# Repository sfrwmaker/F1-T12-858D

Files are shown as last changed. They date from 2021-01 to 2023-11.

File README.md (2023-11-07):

# F1-T12-858D
Soldering station for hakko t12 tips + 858D rework station

The project description is available here: https://www.hackster.io/sfrwmaker/stm32-based-soldering-and-rework-station-e3955b

REVISION HISTORY:

Nov 2019. First release created

Jan 2020. Second release created
  - Minor changes in the controller schematics
  - Now the Hot Air Gun reed switch controls working mode
  - The soldering iron can keep working while Hot Air Gun mode
  - Screen saver feature implemented
  
Jan 2020. Some updates of the second release
  - Minor changes in the controller schematics
  - Buzzer is always on issue fixed

Feb 11 2020. Error on Op-amp label on schematics fixed. LM328 - > LM358

Mar 23 2020. New firmware release, 2.02. See detailed description on the project page.
  - Updated Hot Air Gun cooling procedure
  - Debug mode added allowing monitoring of the internal parameters

Apr 17 2020. New firmware release, 2.03. See detailed description on the project page.
  - Two mode hardware switch supported: REED and TILT. Tilt switch algorithm updated. 
  - Fixed issue 'jammed on tip selection screen'. Now the main menu reacheble from tip selection mode by long press.
  - Ambient temperature and tilt switch readings now are available on debug screen.
  - Controller without soldering handle connected starts working in Hot Air Gun mode.

Apr 29 2020. New firmware release, 3.00. See detailed description on the project page.
  - Optional 220v safety relay added.
  - Rotary encoder acceleration deactivated.

May 12 2020. New firmware release, 3.01. See detailed description on the project page.
  - Standby mode issues fixed.
  - Temperature step feature added.
  
June 03 2020. New firmaware release, 3.02.
  - Hot Air GUN start issue fixed. The power is supplied to the Hot Gun in 1 second after it activated allowing enabling AC relay.
  - "About" menu item issue fixed. Now this menu is available.
  - Tilt switch procedures reviewed and updated.
  - The standby mode separated from main working mode and implemented as a new one.
  - Screen saver timeout now is a single entity. It is no longer depended on mode switching. To return to the normal screen mode, touch the encoder.
  - Software automatic power off procedure reviewed and updated. The controller can power off the iron in case of no tilt switch available.
  - Accelerated mode of rotary encoder implemented in setting low power temperature procedure in the main menu.
  
  Jan 03 2021. New firmware release, 4.00.
  - Display initialization method chhanged. Now the rotation parameter is inside the contstuctor in display.cpp.
  - Added support for 'Guarantee cool gun' feature. New feature requires the hardware to be updated.
    With new hardware schematics the controller guarantees the Hot Air Gun cooled before shutdown.
    You can put Hot Air Gun to the base then switch off the main power switch and leave your working place.
    The controller will switch-off the Hot Air Gun, waits till the Hot Air gun cooled and power-off itself.
    The new firmware release suports old hardware also. Of course, new 'guarantee cool gun feature' will not be available on old hardware.
    
  Jan 30 2021. New hardware and firmware release, 4.01. The schematics with relay has been simplified.
  - Support for 'Guarantee cool gun' feature changed. New feature requires the hardware to be updated. See stm32_T12+858D_v4.sch file in the eagle directory.
  
  Feb 01 2021. Release 4.02.
  - Fixed controller hangs after Hot Air Gun cooled issue.
  
  Apr 28 2021. Release 4.03.
  - Debug information about AC zero events added to the debug mode
  
  May 25 2021. Release 4.04.
  - New feature added. Now it is possible to manage soldering iron while in hot air gun mode. If the "keep iron" option is enabled in main menu, long-press the encoder toggles the soldering iron.
 
  May 30 2021. Release 4.05.
  - Automatic startup mode implemented. The soldering iron would power-up when the power applied to the controller if mode activated.
  - Boost mode updated. Now boost duration time can be increment by 20 seconds upto 320 seconds. Boost mode temperature now more stable.

  Jun 02 2021. Release 4.06
  - No "about" item menu bug fixed
  
  Sep 21 2021. Release 4.07
  - Support for system clock checking procedure added. The controller checks its clock speed at startup. In case the ckock is lower than 72 MHz, the error message will be displayed. To return to the working mode long press the encoder.
  
  Sep 22 2021. Revert to release 4.06
  - The controller speed inialized correctly alwas, the speed test is not necessary.
  - Some followers reported the new firmware does not work.
  - Restore old source files, rebuild the project. Perhaps, the issue is about the flash limit of the stm32 microcontroller.
 
 Apr 01 2022. Release 4.07
 - Rotaruy encoder manager improved
 - New PID parameters for the Hot Air Gun caliration procedure applied
 - New TIP, T12-D32 added to the tip list

 Nov 07 2023. Release 4.08
 - The CubeMX file and project are mirgated to STM32CubeIDE.
 - Implemented new PID algorithm, trying to prevent overheating the soldering iron during heating up.
 - Faster heat-up procedure of soldering iron.
 - New manage procedure for Hot Air Gun imported from my recent project of soldering station with JBC tips.

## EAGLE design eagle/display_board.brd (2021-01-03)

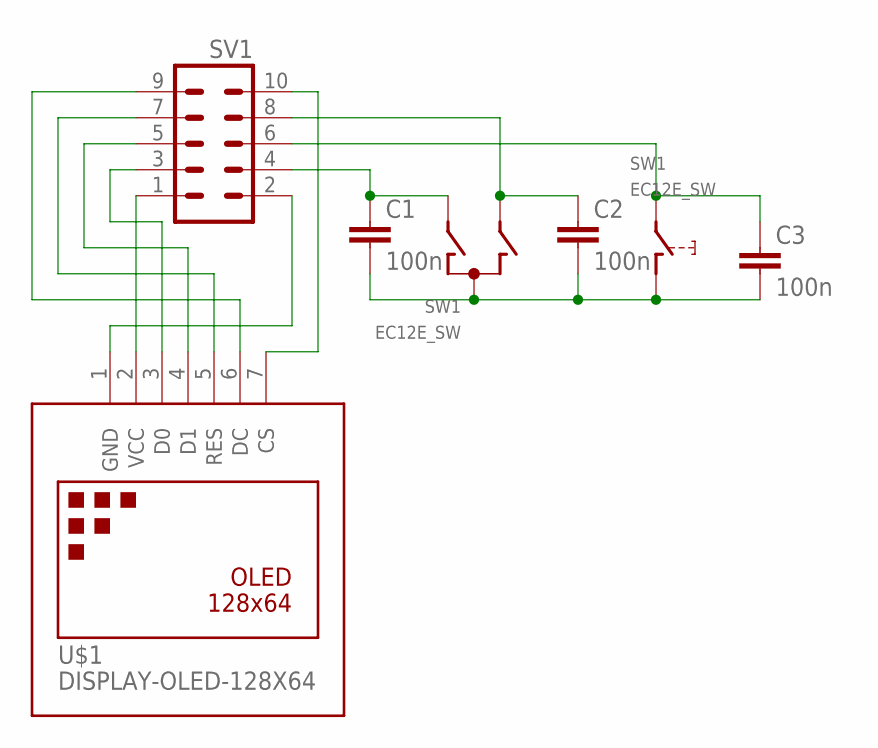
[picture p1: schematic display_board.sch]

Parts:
C1, C2, C3: 100n; C1206
SV1: MA05-2
SW1: EC12E_SW; ALPS_EC12E_SW
U$1: DISPLAY-OLED-128X64

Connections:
unnamed: SV1.1, U$1.2 (VCC)
unnamed: SV1.3, U$1.3 (D0)
unnamed: SV1.5, U$1.4 (D1)
unnamed: SV1.7, U$1.5 (RES)
unnamed: SV1.9, U$1.6 (DC)
unnamed: SV1.2, U$1.1 (GND)
unnamed: C1.1, SV1.4, SW1.A
unnamed: C1.2, C2.2, C3.2, SW1.C, SW1.D (1)
unnamed: C2.1, SV1.8, SW1.B
unnamed: C3.1, SV1.6, SW1.E (2)
unnamed: SV1.10, U$1.7 (CS)

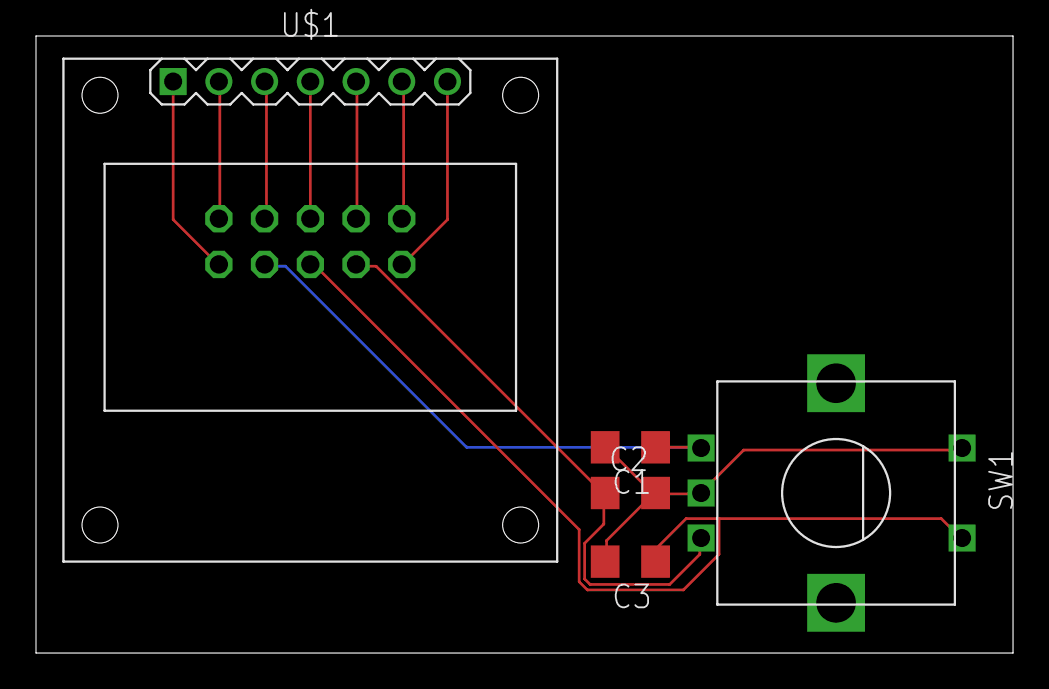
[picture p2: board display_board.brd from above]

Board: 2 copper layers, 54.3 x 34.3 mm, 6 parts (1 on the bottom side), 11 nets.

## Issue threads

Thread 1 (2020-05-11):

Bigger display

Vasilis-7, 2020-05-11:
I am thinking that a bigger display will help. In the market there are some economic color or black & white screens using the driver ILI9341. They have resolution up to 240*320 and 2.8"inches. Is it possible to add support for these ?

daohuaxiang4, 2020-08-12:
Hello! I want to restore the screen to normal display instead of rotating 180°. Which place in the display.cpp file should I modify?

sfrwmaker, 2020-12-20:
Hello!
I have investigated several displays on the market and you are right, the one based on ili9341 chip is the best choice because of variety of sizes: 2.2", 2.4" and 2.8". Yet it has SPI interface and has acceptable performance. The main problem is design. I am working on it, but still have no idea how to show all the parameters. Perhaps, this display can show the iron and hot gun parameters  simultaneously, but i do not know how.

Vasilis-7, 2020-12-22:
Thank you for your answer.
A big display is very useful. Because of that, I had started to make the hot air gun with the arduino and the hot iron with the arduino in the same box using 2 arduino mini pro, connected together through serial. The arduino which control the iron will not use its display, instead of that it will send the information by serial to the other arduino. The last one will send all the information on a LCD display 20 x 4.
But, a bigger display with the features of your project on the STM32 is a great chalenge !!!
I suggest, to use all the display for each unit during setup procedure. The view will be better for the graph. Also if the user is using only one, iron or air gun, you can use all the display with more details or better appearance. If the user wants to use both units, you can split the display horizonticaly with fewer details and simple appearance.
When the user uses only the hot air gun, you can have a tachometer for measuring the current temperature of the hot air gun, in the center like a odometer, the temperature goal, and beside, a second smaller tachometer like turbo indicator for the blower. When the iron is selected,  you can use something like this https://cdn.mos.cms.futurecdn.net/nvLu9ZnCboT3QeZGjo6NXh-970-80.jpg.
When the user needs both units, you can show him simple numbers with text and colors.
You can use colors to display the temperature grades or bars like an equalizer. The air indicator could be like a round pressure indicator with colors.
You can add a timer that will inform the user, in how many minutes or seconds the unit (iron, air gun or both) will turned off
You can have a graphical menu with buttons, a melody with a screen logo or a beautifull icon at startup.
Perhaps, later,  you can add a touch screen support on it.
Add also a software version view in the setup menu.

Vasilis

sfrwmaker, 2021-06-17:
Not an issue

Closed 2021-06-17.

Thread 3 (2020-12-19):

hardware reset when gun working

gyboy, 2020-12-19:
hey, Alexander, I  made one based on your hardware and software .I have changed nothing and it seems work well at the begining,however,when I used the gun for a while,the board automaticlly reset since I haved detected about 10ms low level signal on the reset pin,if I do not use the gun,it seems work well,have you ever met the problem? this IDE is not nice to me and I have problem to debug.

sfrwmaker, 2020-12-20:
Hello!
No one claimed this issue before.
Can you describe the problem in more detail?
How long it takes before switch-on the hot gun and reset event? I believe many followers use this rework station in hot gun mode for a long time and no one claimed such issue before.
How did you detect the 10ms reset (low ?) signal on reset pin? As far as i know, the reset pin is pulled-up on the bluepill board to 3.3v, yet it does not connected to anything else. Also, no watch-dog timer used in the firmware. So it is hard to imagine what is the issue root. I will investigate this issue.

gyboy, 2020-12-21:
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
I just make the station and do not do any calibration before,when I move the gun from the hook , the fan is on and every setting is defalt,(I do not connect thesolder since I just want to check the fan function while the AC zero and relay pin is still work)After about 1min the hardware started reset repetly.I try again today and find that even I remove the gun and just leave the AC zero&delay connect,the station will still reset after about 1min.

> How long it takes before switch-on the hot gun and reset event? I believe many followers use this rework station in hot gun mode for a long time and no one claimed such issue before.
1 min, I forgot to tell you that I just changed 3 pin to fit you T12 project .I modefied GUN_REED_Pin to PA7, ENCODER_R_Pin to PB3 TILT_SW_Pin to PA8 just on main.h since they are just GPIO fuction.Besides,I modified the Encode direction too.

> How did you detect the 10ms reset (low ?) signal on reset pin? As far as i know, the reset pin is pulled-up on the bluepill board to 3.3v, yet it does not connected to anything else. Also, no watch-dog timer used in the firmware. So it is hard to imagine what is the issue root. I will investigate this issue.
I use the oscilloscope and found the low level on reset pin, since my borad has also added the RC delay on reset pin.
besides,when I use the gun menu and select calibration and then push the button to turn on the gun,the sreen will show ERROR after about 6 seconds.

sfrwmaker, 2020-12-21:
Sorry, I cannot debug modified hardware project. Because i have no such hardware.
You can use debug mode to investigate the issue.

gyboy, 2020-12-21:
> Sorry, I cannot debug modified hardware project. Because i have no such hardware.
> You can use debug mode to investigate the issue.

Another strange problem is that the gun temp channel which is PA5 keep zero no matter floating or connect to gun, even connected to 3V3,maybe I should resolve this first.

gyboy, 2020-12-22:
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

hey,bro,I think I have found the problem,but I still have something to enquire you,it looks like the GUN TEMP  ADC doesn't work well even I measured floating voltage on the pin however the buffer can not detect it,I am looking for the problem for futher,maybe other ADC have same problem.I migrate the project to high version,maybe something wrong happened.I want to know have you set the ADC1 and ADC2 global interrupts,since in my cubeMX it is disabled,canyou tell me other settings about ADC too,the pic on the web is not complete,thanks.

sfrwmaker, 2020-12-22:
Hello!
The controller should be tuned in terms of potentiometers R5 and R19. And to debug the hardware problems, you can use debug mode (called through 'About' menu). Here you can see the raw values the controller reads from the hardware.

gyboy, 2020-12-22:
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

thanks,I can not go to turn mode now since when I turn on the gun for a while, hard reset will happened.besides, the ADC is still have problem now. I found this problems just on the About menu.I have made you IRON  project before and it works well ,while when I made this station just use same components,problems met on ADC.It seems ADC hardware is simple,but the soft is a little complex,why you set ADC1 and ADC2 to acquire several channels in different interval while use just one adc and continuosly sample 5 channels in one interrupt

sfrwmaker, 2020-12-22:
Hello!
There is an incorrect call of ADC conversion using DMA in the source code. But it works fine, so i decided to keep this error for a while. Perhaps some day i will release new version where this error will be fixed.
I have tried to change the ADC channels while program work but failed with that so i decided to fix the channels for every measurement. If you check the CubeMX, you can see the ADC1 used to check current through the iron and through fan, gun temperature and ambient temperature. While ADC2 is used to check the iron temperature only. The soldering iron temperature can change quickly so i decided to use average value of 4 temperature samples.

gyboy, 2020-12-25:
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

thanks!
That's the problem ,it seems that all my chips on hand worked not well like yours, I tried to make one same circuit like yours on the bread board,it also doesn't work,the phenomenon is that that gun temp is not update brfore I got in the debug menu,on the main show the gun temp  maintain 25 which is same with NTC ,no matter I connect it to VCC or GND .

I also tried to trance the program,it looked like the "buff[ADC_BUFF_SZ]" catched the right value but updated fail to "gun_temp"
can you describe the error more detaily,I am considering whether I need to use the ADC DMA.

sfrwmaker, 2020-12-26:
Hello!
First, the hardware issues should be fixed. Check the voltage on pins #3 and pin#1 od AD823 op amp. This is a gun temperature. Also, check the voltage on pin #5 and pin#7 of AD823. This is a iron temperature. Then check the voltage on pin #3 and pin #1 of lm358 this should be the current through the hot air gun fan (when the gun activated) and voltage on pins #5 and #7 - this is a current through the iron. Usually, the hardware is a source of all problems in this project. Sometimes the people buy fake op-amps or other components. Another problem can be fake stm32 board. I have several garbage boards based on cks32 micro controller. They are about compatible with stm32, but does not supported by the development tools.

gyboy, 2021-01-19:
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

thanks, I have made sure that the hardware is ok since I have used it on the STM32 T12 project, besides,recently I was studying your code  and tried to do some debug use segger RTT, I disconnect the ADC pin and amp so I can rule out the hardware problem.which means that now the adc pin is float. The result is that the in the "HAL_ADC_ConvCpltCallback" ,I can read the "buff" value and then it should use "core.hotgun.updateTemp(gun_temp);" to update,however ,when I print the "pHG->averageTemp()" in the "MWORK_GUN::loop" function, it stay 0 no matter I turn on the gun or off,but if I go to the "DEBUG" menu,the "pHG->averageTemp()" value will update both in segger RTT and OLED.

sfrwmaker, 2021-01-19:
What exactly do you see on the debug screen?

gyboy, 2021-01-20:
>
>
> What exactly do you see on the debug screen?

I can see the GUN_TEMP jump from 0 to another value,which means before the value is always zero that I can see from segger RTT directly.

gyboy, 2021-02-04:
> What exactly do you see on the debug screen?

Hey,man,I have solved the issue.Cause the input signal has too many noise from the gun that the opm can not process the signal.But there is another problem that I need to enquire you,in the eagle project you use MOC3052 to control the AC line, while MOC3052 has non-zero-cross control but the component symbol in your circuit looks like MOC3062 that has zero-cross detect.The problem I met was that when I connent the heat gun,the AC output is zero,if I disconnected the heat load, the output 220V is ok.I measured the head load is about 70ohm that seems to work well,but I do not know why AC output missed.Could you tell which one do you used,3052 or 3062,thks.

sfrwmaker, 2021-02-04:
Hello!

I used MOC3061 variant. It is not necessary to use zero-cross-detection feature because, there is a zero detector built on 4N25 IC in this project. The know-how is that the Hot Air Gun controller "cuts" whole AC half-period waves starting from zero, then to maximum amplitude and again to zero. The controller detects AC zero crossing time and supplies the power to the MOC3052.
Is the Hot Air Gun Fan rotating? The controller should detect the current through the fan to supply the power the the heater circuit.  To detect the current through the fan, the controller check the voltage drop on R27 resister. Please, check the voltage on pins #3 and #1 of lm358.

gyboy, 2021-02-05:
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

The fan works well and I can change the speed,maybe I should detect the fan current opm output.I have measured the controller zero cross input and heater output,both looks well as shown below.
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

- [ ]

sfrwmaker, 2021-02-06:
Hello!
Did you mean voltage on PA11 pin of bluePill board? For sure, the controller is working fine. Please check your TRIAC cirquit.

sfrwmaker, 2021-06-17:
Fixed

Closed 2021-06-17.

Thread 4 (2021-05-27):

JBC 210 245  iron support

mojinyinhu, 2021-05-27:
hi，Can you add JBC 210 245 iron core support？

sfrwmaker, 2021-05-27:
Not planned. Usually universal tool is worse than dedicated one.

mojinyinhu, 2021-06-05:
936 jbc245 jbc210 these are all 24 V power supply. Under the current circuit, we can detect the resistance value of the heating core of these soldering irons, do automatic detection, and automatically adapt to the maximum power. At present, we see that the general welding platform (supporting 936, T12, JBC) circuit is PWM control scheme, and there are also related products. We hope that we can adapt the software to make the general welding platform, and the power of t12 72w is limited after all, It's not easy to deal with large solder joints. 245 150W power is very good, and the temperature recovery effect is also very good.  hope this scheme can be considered

The attachment is a reference scheme
[Uploading 四合一JBC  T12 936 OLED1.3寸 工作等级焊台资料.zip…]()

sfrwmaker, 2021-06-17:
Not an issue.

Closed 2021-06-17.

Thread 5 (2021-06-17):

can you add 3 memory state like quick station

labotecno, 2021-06-17:
hello i see your project  and i like it , can you add 3 or 4 memory state , for heat gun like quick hot air station ?

sfrwmaker, 2021-06-17:
It is much convenient to discuss the project on hackster.io. :)

sfrwmaker, 2021-06-17:
Not an issue

Closed 2021-06-17.

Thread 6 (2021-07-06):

exclude private variable i_summ

enjoyneering, 2021-07-06:
Why keep "i_summ" in memory when it always changes and used locally in PID::reqPower()?

sfrwmaker, 2021-07-06:
Perhaps, this variable used in beta version or so. Just did not optimized.:) Will be fixed in future release or in future project.
Thank you for your report.

enjoyneering, 2021-07-07:
Good. Thank you for awesome project.

Closed 2021-07-07.

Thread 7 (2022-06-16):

PID control strategy，Temperature overshoot of air gun soldering iron

mojinyinhu, 2022-06-16:
hello，If it is found that the temperature of the air gun soldering iron is overshoot, can the segmented PID be modified and used: when the temperature difference is >100 ℃, heat at full speed; Radical PID when the temperature difference is 30~100 ℃; Conservative PID when temperature difference <30 ℃;

sfrwmaker, 2022-06-16:
This strategy does not work.

sfrwmaker, 2024-01-12:
New firmware manages the soldering iron and hot air gun more accurately.

Closed 2024-01-12.

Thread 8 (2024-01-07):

can have only T12 firmware binary use?

myvcgit, 2024-01-07:
i had F1-T12-858D pcb and finished t12 part, but this  firmware work incorrect.
can we have only t12 firmware for this pcb?
thank you!

sfrwmaker, 2024-01-07:
Can you describe the issue in more details? What exactly is working incorrectly?
And no, the firmware was developed for described hardware. If you do not want to use hot air gun, you can choose another project. Please see on hackster.io, there are many other soldering projects using Hakko T12 tips.

myvcgit, 2024-01-13:
thank you.
i found ur t12 project.
https://github.com/sfrwmaker/hakko_t12_stm32

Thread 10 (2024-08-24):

STM32CubeIDE compilation error,

daohuaxiang4, 2024-08-24:
Hope to write a correct compilation process to help me

sfrwmaker, 2024-08-25:
Can you contact me at hackster.io, please? You can write a private message to me or post new comment in the project discussion page.

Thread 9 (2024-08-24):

STM32CubeIDE compilation error, want to write a correct compilation process

daohuaxiang4, 2024-08-24:

Closed 2024-08-24.

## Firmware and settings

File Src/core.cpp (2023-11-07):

/*
 * core.cpp
 *
 *  Created on: 30 aug 2019
 *      Author: Alex
 */

#include <string.h>
#include "core.h"
#include "hw.h"
#include "mode.h"
#include "stat.h"
#include "oled.h"
#include "tools.h"
#include "buzzer.h"

#include "display.h"
#include <math.h>

#define ADC_CONV 	(4)										// Activated ADC Ranks Number (hadc2.Init.NbrOfConversion)
#define ADC_LOOPS	(2)										// Number of ADC conversion loops. Should be even
#define ADC_BUFF_SZ	(2*ADC_CONV*ADC_LOOPS)

extern ADC_HandleTypeDef	hadc1;
extern ADC_HandleTypeDef	hadc2;
extern TIM_HandleTypeDef	htim1;
extern TIM_HandleTypeDef	htim2;
extern TIM_HandleTypeDef	htim4;

typedef enum { ADC_IDLE, ADC_CURRENT, ADC_TEMP } t_ADC_mode;
volatile static t_ADC_mode	adc_mode = ADC_IDLE;
volatile static uint16_t	buff[ADC_BUFF_SZ];
volatile static	uint32_t	tim1_cntr	= 0;				// Previous value of TIM1 counter. Using to check the TIM1 value changing
volatile static	bool		ac_sine		= false;			// Flag indicating that TIM1 is driven by AC power interrupts on AC_ZERO pin
volatile static uint8_t		check_count	= 1;				// Decrement from check_period to zero by TIM2. When become zero, force to check the IRON connectivity
volatile static bool		clock_ok	= true;				// Flag indicating the system clock is working at 72 MHz (see RTC_IRQHandler()
const static uint16_t  		max_iron_pwm	= 1960;			// Max value should be less than TIM2.CHANNEL3 value by 20
const static uint16_t  		max_gun_pwm		= 99;			// TIM1 period. Full power can be applied to the HOT GUN
const static uint16_t		check_iron_pwm	= 1;			// This power should be applied to check the current through the IRON
const static uint8_t		check_period	= 6;			// TIM2 loops between check current through the iron
const static	uint32_t	check_sw_period = 100;			// IRON switches check period, ms

static HW		core;										// Hardware core (including all device instances)

// MODE instances
static	MSTBY_IRON		standby_iron(&core);
static	MWORK_IRON		work_iron(&core);
static  MLOW_POWER		low_power(&core);
static	MBOOST			boost(&core);
static	MSLCT			select(&core);
static	MTACT			activate(&core);
static	MCALIB			calib_auto(&core);
static	MCALIB_MANUAL	calib_manual(&core);
static	MCALMENU		calib_menu(&core, &calib_auto, &calib_manual);
static	MTUNE			tune(&core);
static	MFAIL			fail(&core);
static	MMBST			boost_setup(&core);
static	MTPID			pid_tune(&core);
static	MENU_GUN		gun_menu(&core, &calib_manual, &tune, &pid_tune);
static	MWORK_GUN		work_gun(&core);
static  MABOUT			about(&core);
static  MDEBUG			debug(&core);
static	MMENU			main_menu(&core, &boost_setup, &calib_menu, &activate, &tune, &pid_tune, &gun_menu, &about);
static	MODE*           pMode = &standby_iron;

bool isACsine(void) 	{ return ac_sine; }

// Synchronize TIM2 timer to AC power
uint16_t syncAC(void) {
	uint32_t to = HAL_GetTick() + 300;						// The timeout
	uint16_t nxt_tim1	= TIM1->CNT + 2;
	if (nxt_tim1 > 99) nxt_tim1 -= 99;						// TIM1 is clocked by AC zero crossing signal, period is 99.
	while (HAL_GetTick() < to) {							// Prevent hang
		if (TIM1->CNT == nxt_tim1) {
			TIM2->CNT = 0;									// Synchronize TIM2 to AC power zero crossing signal
			break;
		}
	}
	// Checking the TIM2 has been synchronized
	to = HAL_GetTick() + 300;
	nxt_tim1 = TIM1->CNT + 2;
	if (nxt_tim1 > 99) nxt_tim1 -= 99;
	while (HAL_GetTick() < to) {
		if (TIM1->CNT == nxt_tim1) {
			return TIM2->CNT;
		}
	}
	return TIM2->ARR+1;										// This value is bigger than TIM2 period, the TIM2 has not been synchronized
}

void SCRSAVER::reset(void) {
	if (to > 0) {
		scr_save_ms = HAL_GetTick() + (uint32_t)to * 60000;
	} else {
		scr_save_ms = 0;								// Disable screen saver
	}
	scr_saver = false;
}

bool SCRSAVER::scrSaver(void) {
    if (scr_save_ms && !scr_saver && HAL_GetTick() >= scr_save_ms) {
    	scr_saver = true;
    }
    return scr_saver;
}

CFG_STATUS HW::init(void) {
	dspl.init();
	iron.init();
	hotgun.init();
	encoder.addButton(ENCODER_B_GPIO_Port, ENCODER_B_Pin);
	CFG_STATUS cfg_init = 	cfg.init();
	PIDparam pp   		= 	cfg.pidParams(true);			// load IRON PID parameters
	iron.load(pp);
	pp					=	cfg.pidParams(false);			// load Hot Air Gun PID parameters
	hotgun.load(pp);
	buzz.activate(cfg.isBuzzerEnabled());
	scrsaver.init(cfg.getScrTo());							// Screen saver timeout can be reloaded via main menu, see MMENU::loop()
	return cfg_init;
}

extern "C" void setup(void) {
	CFG_STATUS cfg_init = core.init();						// Initialize the hardware structure before start timers

	HAL_ADCEx_Calibration_Start(&hadc1);					// Calibrate both ADCs
	HAL_ADCEx_Calibration_Start(&hadc2);
	HAL_TIM_PWM_Start(&htim1, TIM_CHANNEL_4);				// PWM signal of Hot Air Gun
	HAL_TIM_OC_Start_IT(&htim1,  TIM_CHANNEL_3);			// Calculate power of Hot Air Gun interrupt
	HAL_TIM_PWM_Start(&htim2, TIM_CHANNEL_1);				// PWM signal of the IRON
	HAL_TIM_PWM_Start(&htim2, TIM_CHANNEL_2);				// PWM signal of FAN (Hot Air Gun)
	HAL_TIM_OC_Start_IT(&htim2,  TIM_CHANNEL_3);			// Check the current through the IRON and FAN, also check ambient temperature
	HAL_TIM_OC_Start_IT(&htim2,  TIM_CHANNEL_4);			// Calculate power of the IRON
	HAL_TIM_PWM_Start(&htim4,    TIM_CHANNEL_4);			// PWM signal for the buzzer

	// Setup main mode parameters: return mode, short press mode, long press mode
	standby_iron.setup(&select, &work_iron, &main_menu);
	work_iron.setup(&standby_iron, &standby_iron, &boost);
	low_power.setup(&standby_iron, &work_iron, &work_iron);
	boost.setup(&work_iron, &work_iron, &work_iron);
	select.setup(&standby_iron, &activate, &main_menu);
	activate.setup(&standby_iron, &standby_iron, &main_menu);
	calib_auto.setup(&standby_iron, &standby_iron, &standby_iron);
	calib_manual.setup(&calib_menu, &standby_iron, &standby_iron);
	calib_menu.setup(&standby_iron, &standby_iron, &standby_iron);
	tune.setup(&standby_iron, &standby_iron, &standby_iron);
	fail.setup(&standby_iron, &standby_iron, &standby_iron);
	boost_setup.setup(&main_menu, &main_menu, &standby_iron);
	pid_tune.setup(&standby_iron, &standby_iron, &standby_iron);
	gun_menu.setup(&main_menu, &standby_iron, &standby_iron);
	main_menu.setup(&standby_iron, &standby_iron, &standby_iron);
	about.setup(&standby_iron, &standby_iron, &debug);
	debug.setup(&standby_iron, &standby_iron, &standby_iron);

	standby_iron.setGunMode(&work_gun);
	work_iron.setGunMode(&work_gun);
	work_iron.setLowPowerMode(&low_power);
	work_gun.setIronModes(&standby_iron, &work_iron);

	switch (cfg_init) {
		case	CFG_NO_TIP:
			pMode	= &activate;							// No tip configured, run tip activation menu
			break;
		case	CFG_READ_ERROR:								// Failed to read EEPROM
			core.dspl.errorMessage("EEPROM\nread\nerror");
			pMode	= &fail;
			break;
		default:
			if (core.cfg.isAutoStart())
				pMode = &work_iron;
			break;
	}

	syncAC();												// Synchronize TIM2 timer to AC power
	HAL_Delay(1000);										// Wait till hardware status updated
	pMode->init();
}


extern "C" void loop(void) {
	static uint32_t AC_check_time	= 0;					// Time in ms when to check TIM1 is running
	static uint32_t	check_sw		= 0;					// Time when check iron switches status (ms)

	if (HAL_GetTick() > check_sw) {
		check_sw = HAL_GetTick() + check_sw_period;
		GPIO_PinState pin = HAL_GPIO_ReadPin(TILT_SW_GPIO_Port, TILT_SW_Pin);
		core.iron.updateReedStatus(GPIO_PIN_SET == pin);		// Update T12 TILT switch status
		pin = HAL_GPIO_ReadPin(GUN_REED_GPIO_Port, GUN_REED_Pin);
		core.hotgun.updateReedStatus(GPIO_PIN_SET == pin);	// Switch active when the Hot Air Gun handle is off-hook
	}

	MODE* new_mode = pMode->returnToMain();
	if (new_mode && new_mode != pMode) {
		core.buzz.doubleBeep();
		core.iron.switchPower(false);
		TIM2->CCR1	= 0;
		pMode = new_mode;
		pMode->init();
		return;
	}
	new_mode = pMode->loop();
	if (new_mode != pMode) {
		if (new_mode == 0) new_mode = &fail;				// Mode Failed
		core.iron.switchPower(false);
		core.hotgun.switchPower(false);
		TIM2->CCR1	= 0;
		pMode = new_mode;
		pMode->init();
	}

	// If TIM1 counter has been changed since last check, we received AC_ZERO events from AC power
	if (HAL_GetTick() >= AC_check_time) {
		ac_sine		= (TIM1->CNT != tim1_cntr);
		tim1_cntr	= TIM1->CNT;
		AC_check_time = HAL_GetTick() + 41;					// 50Hz AC line generates 100Hz events. The pulse period is 10 ms
	}
}

static bool adcStart(t_ADC_mode mode) {
    if (adc_mode != ADC_IDLE) {								// Not ready to check analog data; Something is wrong!!!
    	TIM2->CCR1 = 0;										// Switch off the IRON
    	TIM1->CCR4 = 0;										// Switch off the Hot Air Gun
		return false;
    }
	HAL_ADC_Start(&hadc2);
    HAL_ADCEx_MultiModeStart_DMA(&hadc1, (uint32_t*)buff, ADC_CONV*ADC_LOOPS);
	adc_mode = mode;
	return true;
}

/*
 * IRQ handler
 * on TIM1 Output channel #3 to calculate required power for Hot Air Gun
 * on TIM2 Output channel #3 to read the current through the IRON and Fan of Hot Air Gun
 * also check that TIM1 counter changed driven by AC_ZERO interrupt
 * on TIM2 Output channel #4 to read the IRON, HOt Air Gun and ambient temperatures
 */
extern "C" void HAL_TIM_OC_DelayElapsedCallback(TIM_HandleTypeDef *htim) {
	if (htim->Instance == TIM1 && htim->Channel == HAL_TIM_ACTIVE_CHANNEL_3) {
		uint16_t gun_power	= core.hotgun.power();
		TIM1->CCR4	= constrain(gun_power, 0, max_gun_pwm);
	}
	if (htim->Instance == TIM2) {
		if (htim->Channel == HAL_TIM_ACTIVE_CHANNEL_3) {
			if (TIM2->CCR1 || TIM2->CCR2)					// If IRON of Hot Air Gun has been powered
				adcStart(ADC_CURRENT);
		} else if (htim->Channel == HAL_TIM_ACTIVE_CHANNEL_4) {
			adcStart(ADC_TEMP);
		}
	}
}

/*
 * IRQ handler of ADC complete request. The data is in the ADC buffer (buff)
 * Data read by 8 slots interleaved: adc1-rank1, adc2-rank1, adc1-rank2, adc2-rank2, ..., adc1-rank4, adc2-rank4
 * The ADC buffer would have the following fields (see MX_ADC1_Init() MX_ADC2_Init() in main.c)
 * ADC1:			ADC2:
 * iron_current		iron_temp
 * fan_current		iron_temp
 * gun_temp			iron_temp
 * ambient			iron_temp
 */
extern "C" void HAL_ADC_ConvCpltCallback(ADC_HandleTypeDef* hadc) {
	if (hadc->Instance != ADC1) return;
	HAL_ADCEx_MultiModeStop_DMA(&hadc1);
	HAL_ADC_Stop(&hadc2);
	if (adc_mode == ADC_TEMP) {								// Read the temperatures only, the current should be ignored
		volatile uint32_t iron_temp	= 0;
		volatile uint32_t gun_temp	= 0;
		volatile uint32_t ambient 	= 0;
		for (uint8_t i = 0; i < ADC_BUFF_SZ; i += 2*ADC_CONV) {
			iron_temp	+= buff[i+1] + buff[i+3] + buff[i+5] + buff[i+7];
			gun_temp	+= buff[i+4];
			ambient		+= buff[i+6];
		}
		iron_temp 	+= (ADC_LOOPS*ADC_CONV)/2;				// Round the result
		iron_temp 	/= ADC_LOOPS*ADC_CONV;
		gun_temp 	+= ADC_LOOPS/2;							// Round the result
		gun_temp  	/= ADC_LOOPS;
		ambient 	+= ADC_LOOPS/2;							// Round the result
		ambient  	/= ADC_LOOPS;
		core.iron.updateAmbient(ambient);

		uint8_t min_iron_pwm = 0;							// By default do not power the IRON to check connectivity
		if (--check_count == 0) {							// It is time to check IRON is connected or not
			check_count	= check_period;
			min_iron_pwm = check_iron_pwm;
		}
		if (core.iron.isConnected()) {
			uint16_t iron_power = core.iron.power(iron_temp);
			TIM2->CCR1	= constrain(iron_power, min_iron_pwm, max_iron_pwm);

		} else {
			TIM2->CCR1	= min_iron_pwm;						// Sometimes supply minimum power to the IRON to check connectivity
		}
		core.hotgun.updateTemp(gun_temp);					// Update average Hot Air Gun temperature. Apply the power by TIM1.CNANNEL3 interrupt
	} else if (adc_mode == ADC_CURRENT) {					// Read the currents, the temperatures should be ignored
		volatile uint32_t iron_curr	= 0;
		volatile uint32_t fan_curr 	= 0;
		for (uint8_t i = 0; i < ADC_BUFF_SZ; i += 2*ADC_CONV) {
			iron_curr	+= buff[i];
			fan_curr	+= buff[i+2];
		}
		iron_curr	+= ADC_LOOPS/2;							// Round the result
		iron_curr	/= ADC_LOOPS;
		fan_curr	+= ADC_LOOPS/2;							// Round the result
		fan_curr	/= ADC_LOOPS;

		if (TIM2->CCR1)										// If IRON has been powered
			core.iron.updateCurrent(iron_curr);
		if (TIM2->CCR2)										// If Hot Air Gun Fan has been powered
			core.hotgun.updateCurrent(fan_curr);
	}
	adc_mode = ADC_IDLE;
}

extern "C" void HAL_ADC_ErrorCallback(ADC_HandleTypeDef *hadc) 				{ }
extern "C" void HAL_ADC_LevelOutOfWindowCallback(ADC_HandleTypeDef *hadc) 	{ }

// Encoder Rotated
extern "C" void EXTI0_IRQHandler(void) {
	core.encoder.encoderIntr();
	__HAL_GPIO_EXTI_CLEAR_IT(ENCODER_L_Pin);
}

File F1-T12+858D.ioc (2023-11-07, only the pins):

Mcu.UserName=STM32F103C8Tx
PA0-WKUP.GPIO_Label=IRON_POWER
PA0-WKUP.Signal=S_TIM2_CH1_ETR
PA1.GPIO_Label=FAN_POWER
PA1.Signal=S_TIM2_CH2
PA10.GPIO_Label=OLED_CS
PA10.Signal=GPIO_Output
PA11.GPIO_Label=GUN_POWER
PA11.Signal=S_TIM1_CH4
PA12.GPIO_Label=AC_ZERO
PA12.Signal=S_TIM1_ETR
PA13.Signal=SYS_JTMS-SWDIO
PA14.Signal=SYS_JTCK-SWCLK
PA15.GPIO_Label=AC_RELAY
PA15.Signal=GPIO_Output
PA2.GPIO_Label=IRON_CURRENT
PA2.Signal=ADCx_IN2
PA3.GPIO_Label=FAN_CURRENT
PA3.Signal=ADCx_IN3
PA4.GPIO_Label=IRON_TEMP
PA4.Signal=ADCx_IN4
PA5.GPIO_Label=GUN_TEMP
PA5.Signal=ADCx_IN5
PA6.GPIO_Label=AMBIENT
PA6.Signal=ADCx_IN6
PA8.GPIO_Label=GUN_REED
PA8.Signal=GPIO_Input
PA9.GPIO_Label=ENCODER_R
PA9.Signal=GPIO_Input
PB0.GPIO_Label=ENCODER_L
PB0.Signal=GPXTI0
PB1.GPIO_Label=ENCODER_B
PB1.Signal=GPIO_Input
PB10.GPIO_Label=OLED_RESET
PB10.Signal=GPIO_Output
PB11.GPIO_Label=OLED_DC
PB11.Signal=GPIO_Output
PB13.GPIO_Label=OLED_SCK
PB13.Signal=SPI2_SCK
PB15.GPIO_Label=OLED_SDA
PB15.Signal=SPI2_MOSI
PB3.GPIO_Label=TILT_SW
PB3.Signal=GPIO_Input
PB6.Signal=I2C1_SCL
PB7.Signal=I2C1_SDA
PB9.GPIO_Label=BUZZER
PB9.Signal=S_TIM4_CH4
PD0-OSC_IN.Signal=RCC_OSC_IN
PD1-OSC_OUT.Signal=RCC_OSC_OUT

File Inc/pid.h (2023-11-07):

/*
 * pid.h
 *
 *  Created on: 13 ���. 2019 �.
 *      Author: Alex
 */

#ifndef _PID_H
#define _PID_H

#include "main.h"
#include "stat.h"
#include "vars.h"

class PIDparam {
	public:
		PIDparam(int32_t Kp = 0, int32_t Ki = 0, int32_t Kd = 0);
		PIDparam(const PIDparam &p);
		int32_t	Kp					= 0;
		int32_t	Ki					= 0;
		int32_t	Kd					= 0;
};


/*  The PID algorithm 
 *  Un = Kp*(Xs - Xn) + Ki*summ{j=0; j<=n}(Xs - Xj) + Kd(Xn - Xn-1),
 *  Where Xs - is the setup temperature, Xn - the temperature on n-iteration step
 *  In this program the interactive formula is used:
 *    Un = Un-1 + Kp*(Xn-1 - Xn) + Ki*(Xs - Xn) + Kd*(Xn-2 + Xn - 2*Xn-1)
 *  With the first step:
 *  U0 = Kp*(Xs - X0) + Ki*(Xs - X0); Xn-1 = Xn;
 *  
 *  The default values of PID coefficients can be found in config.cpp
 */
class PID {
	public:
		PID(void) 											{ }
		void		load(const PIDparam &p);
		PIDparam	dump(void)								{ return PIDparam(Kp, Ki, Kd);			}
		void		pidStable(int32_t power)				{ this->power = power;					}
		void		init(uint16_t ms, uint8_t denominator_p = 11, bool heat_force = true);
		void 		resetPID(uint16_t t = 0);        		// reset PID algorithm history parameters
		int32_t 	reqPower(int16_t temp_set, int16_t temp_curr);
		int32_t  	changePID(uint8_t p, int32_t k);    	// set or get (if parameter < 0) PID parameter
		void		newPIDparams(uint16_t delta_power, uint32_t diff, uint32_t period);
	private:
		void  		debugPID(int t_set, int t_curr, long kp, long ki, long kd, long delta_p);
		uint32_t 	T 				= 20;					// Check IRON or Hot Air Gun period, ms (to calculate auto PID parameters)
		int16_t   	temp_h0			= 0;					// previously measured temperatures
		int16_t	  	temp_h1			= 0;
		int32_t  	power			= 0;					// The power iterative multiplied by denominator
		int32_t  	Kp 				= 10;					// The PID coefficients multiplied by denominator.
		int32_t     Ki 				= 10;
		int32_t		Kd				= 0;
		int32_t		Kp_force		= 10;					// Kp * 5
		int32_t		Ki_force		= 5;					// Ki / 10
		int16_t  	denominator_p	= 11;              		// The common coefficient denominator power of 2 (11 means 2048)
		bool		use_force		= true;					// Flag indicating to use forcibly heating mode
};

class PIDTUNE {
	public:
		PIDTUNE(void) : period(auto_pid_hist_length), temp_max(auto_pid_hist_length), temp_min(auto_pid_hist_length)		{ 	}
		void		start(uint16_t base_pwr, uint16_t delta_power, uint16_t base_temp, uint16_t delta_temp);
		uint16_t	run(uint32_t t);
		uint16_t	autoTuneLoops(void)						{ return loops; 						}
		uint32_t	autoTunePeriod(void)					{ return period.read();					}
		uint16_t	tempMin(void)							{ return temp_min.read();   			}
		uint16_t	tempMax(void)							{ return temp_max.read();   			}
		bool		periodStable(void);
	private:
		HIST		period;									// Average value of relay method oscillations period
		HIST		temp_max;								// Average value of maximum temperature
		HIST		temp_min;								// Average value of minimum temperature
		volatile	uint16_t	base_power		= 0;		// Base power value
		volatile 	uint16_t 	delta_power		= 0;		// PLUS delta power applied
		volatile	uint16_t	base_temp		= 0;		// Base temperature value
		volatile	uint16_t	delta_temp		= 0;		// The temperature limit (base_temp - delta_temp <= t <= base_temp + delta_temp)
		volatile	bool		app_delta_power	= false;	// Do apply delta power
		volatile	uint32_t	pwr_change		= 0;		// The time (ms) when tune extra power changed
		volatile	bool		check_max		= false;
		volatile	bool		check_min		= false;
		volatile 	uint16_t	t_max			= 0;
		volatile    uint16_t	t_min			= 0;
		volatile	uint16_t	loops			= 0;		// Whole tune oscillation loop count
};

#endif

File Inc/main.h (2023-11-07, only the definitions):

#define IRON_POWER_Pin GPIO_PIN_0
#define IRON_POWER_GPIO_Port GPIOA
#define FAN_POWER_Pin GPIO_PIN_1
#define FAN_POWER_GPIO_Port GPIOA
#define IRON_CURRENT_Pin GPIO_PIN_2
#define IRON_CURRENT_GPIO_Port GPIOA
#define FAN_CURRENT_Pin GPIO_PIN_3
#define FAN_CURRENT_GPIO_Port GPIOA
#define IRON_TEMP_Pin GPIO_PIN_4
#define IRON_TEMP_GPIO_Port GPIOA
#define GUN_TEMP_Pin GPIO_PIN_5
#define GUN_TEMP_GPIO_Port GPIOA
#define AMBIENT_Pin GPIO_PIN_6
#define AMBIENT_GPIO_Port GPIOA
#define ENCODER_L_Pin GPIO_PIN_0
#define ENCODER_L_GPIO_Port GPIOB
#define ENCODER_L_EXTI_IRQn EXTI0_IRQn
#define ENCODER_B_Pin GPIO_PIN_1
#define ENCODER_B_GPIO_Port GPIOB
#define OLED_RESET_Pin GPIO_PIN_10
#define OLED_RESET_GPIO_Port GPIOB
#define OLED_DC_Pin GPIO_PIN_11
#define OLED_DC_GPIO_Port GPIOB
#define OLED_SCK_Pin GPIO_PIN_13
#define OLED_SCK_GPIO_Port GPIOB
#define OLED_SDA_Pin GPIO_PIN_15
#define OLED_SDA_GPIO_Port GPIOB
#define GUN_REED_Pin GPIO_PIN_8
#define GUN_REED_GPIO_Port GPIOA
#define ENCODER_R_Pin GPIO_PIN_9
#define ENCODER_R_GPIO_Port GPIOA
#define OLED_CS_Pin GPIO_PIN_10
#define OLED_CS_GPIO_Port GPIOA
#define GUN_POWER_Pin GPIO_PIN_11
#define GUN_POWER_GPIO_Port GPIOA
#define AC_ZERO_Pin GPIO_PIN_12
#define AC_ZERO_GPIO_Port GPIOA
#define AC_RELAY_Pin GPIO_PIN_15
#define AC_RELAY_GPIO_Port GPIOA
#define TILT_SW_Pin GPIO_PIN_3
#define TILT_SW_GPIO_Port GPIOB
#define BUZZER_Pin GPIO_PIN_9
#define BUZZER_GPIO_Port GPIOB
#define FW_VERSION	("4.08")

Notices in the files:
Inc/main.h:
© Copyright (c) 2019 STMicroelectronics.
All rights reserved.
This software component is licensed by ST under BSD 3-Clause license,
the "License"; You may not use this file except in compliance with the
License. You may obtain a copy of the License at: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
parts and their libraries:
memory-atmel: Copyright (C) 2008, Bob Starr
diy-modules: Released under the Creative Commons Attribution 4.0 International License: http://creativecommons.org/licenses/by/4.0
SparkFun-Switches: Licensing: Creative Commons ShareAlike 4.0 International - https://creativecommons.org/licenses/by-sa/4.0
